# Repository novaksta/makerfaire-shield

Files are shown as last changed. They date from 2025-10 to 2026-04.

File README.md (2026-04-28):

# Game console shield for NUCLEO-F412ZG

It is intended for [MakeCode Arcade](https://arcade.makecode.com/) as F4 target (see available material on (https://arcade.makecode.com/hardware/adding) if you wish to customize),

with additional [lcd module](https://www.laskakit.cz/128x160-barevny-lcd-tft-displej-1-8--spi/)

Available are [bootloader firmware binaries](bootloaders/v2-st7735/bootloader.bin)

There is available kicad project for the board in [pcb foler](pcb) (including [gerbers with BOM](pcb/jlcpcb/production_files/production_files-min.7z) in jlcpcb-friendly format).

There are available [workshop slides](slajdy.pdf) for Maker Faire in Prague 2026 (in czech language) that describes "getting started" process. 

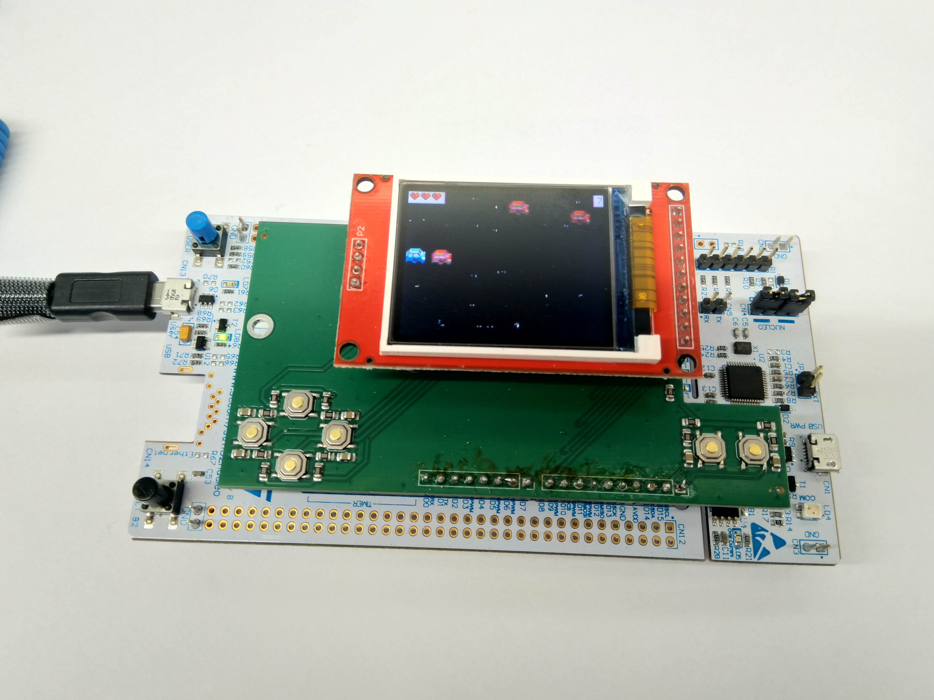
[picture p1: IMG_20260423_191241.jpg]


There are also available workshop materials for Maker Faire in Brno 2025 where used NUCLEO-F411RE/NUCLEO-F401RE -- please see releases section. 

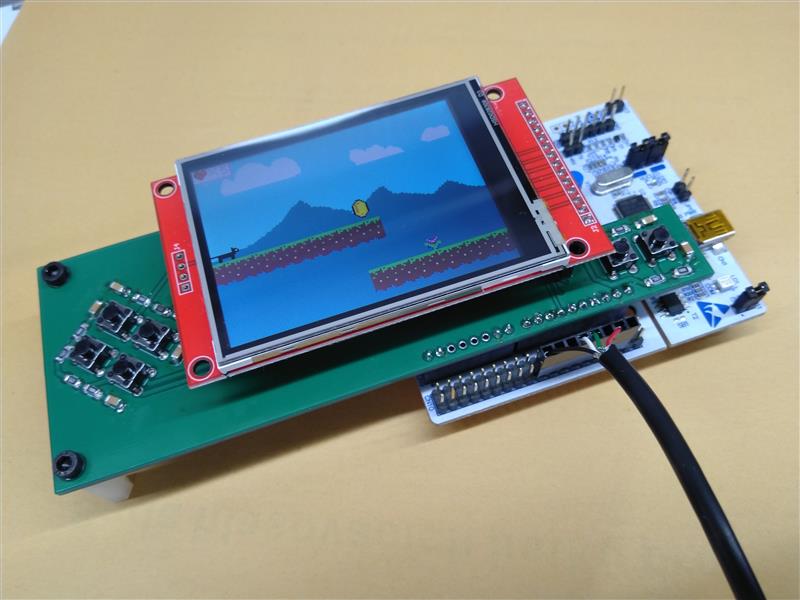
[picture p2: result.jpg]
The result equipped with modules


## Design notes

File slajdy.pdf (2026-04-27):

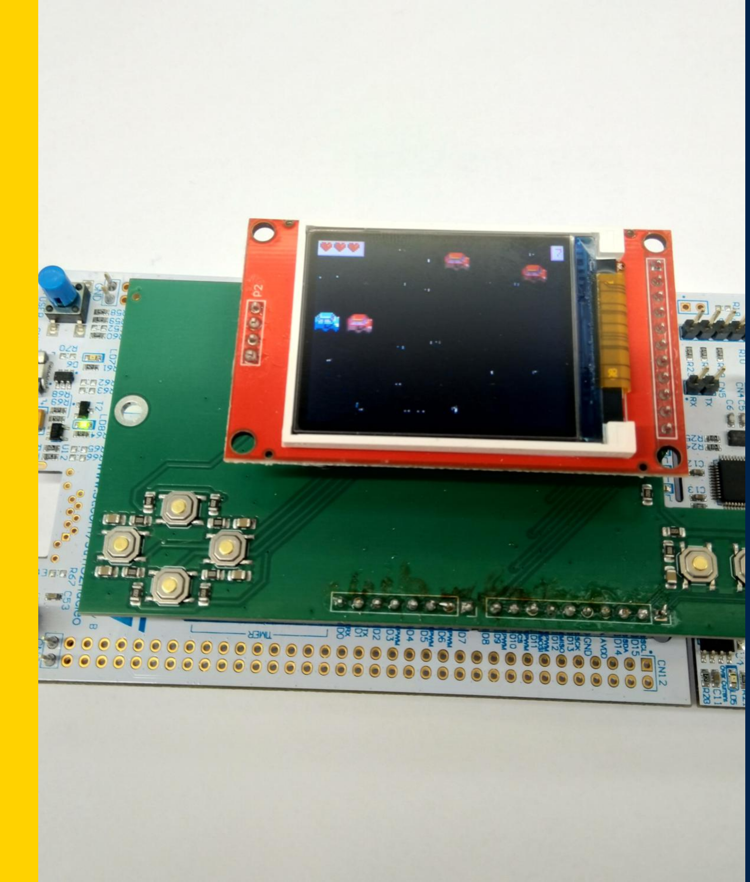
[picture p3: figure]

## Postav a naprogramuj si vlastní herní konzoli s mikrokontrolérem STM32!

Stanislav NOVAK

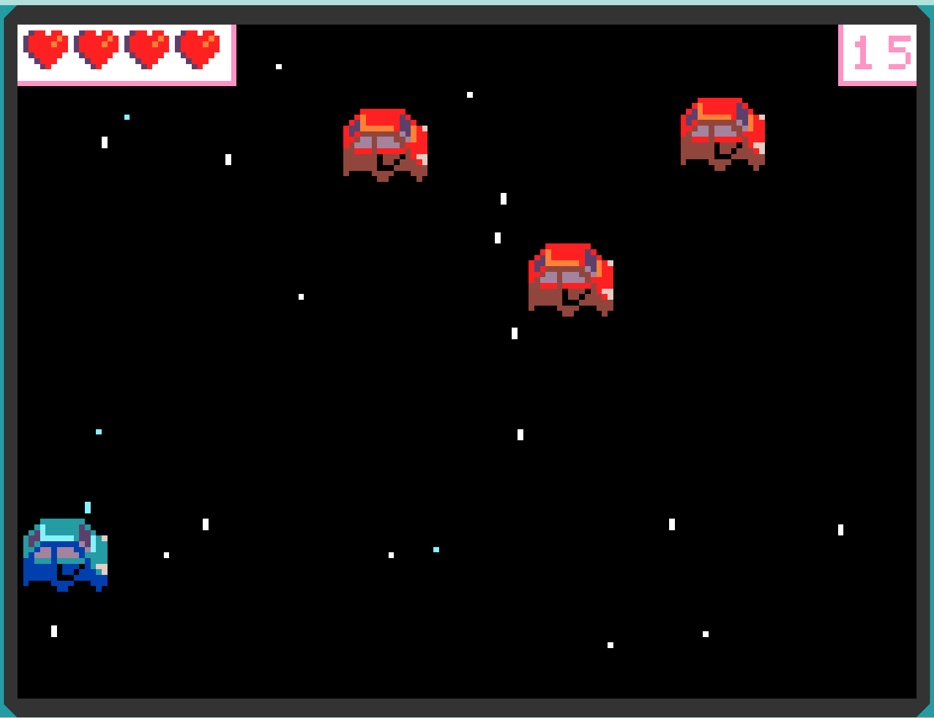
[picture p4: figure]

1

## Agenda

Úvod, predstavení

1.1 | MakeCode Arcade, software
1.2 | Platforma, hardware
2 | Samotný workshop

## Úvod

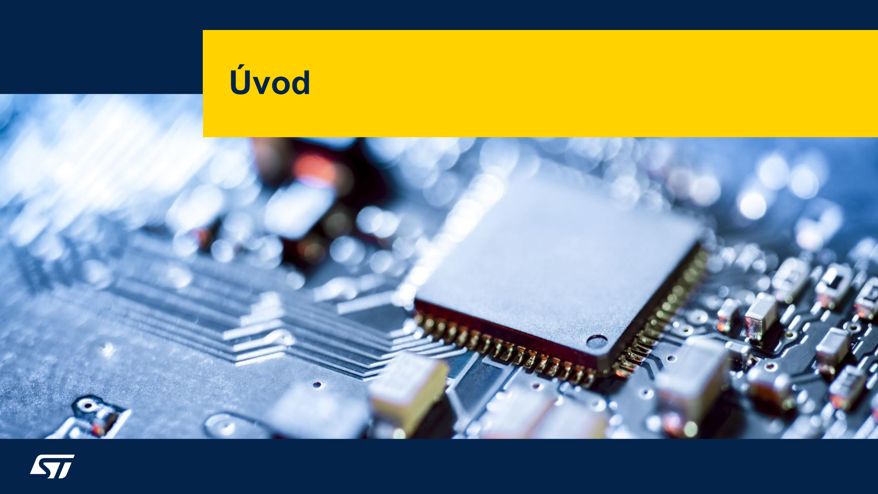
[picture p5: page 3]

## Představení

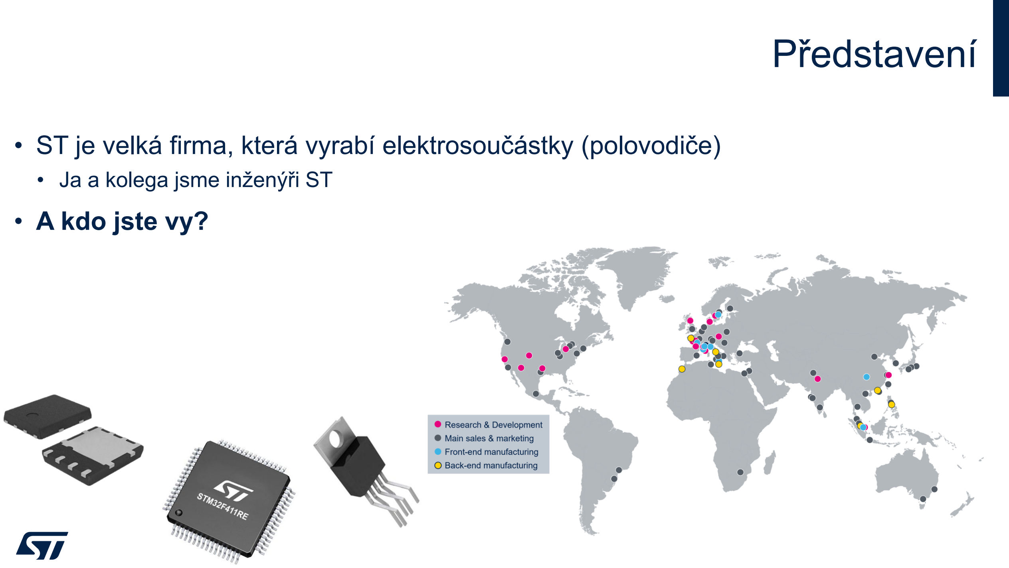
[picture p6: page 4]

- ST je velká firma, která vyrabí elektrosoučástky (polovodiče)
- Ja a kolega jsme inženýři ST
- A kdo jste vy?

- Vyukové prostredí od Microsoftu
- Grafické programovaní, nebo textové (json, python)
- Snadný začátek – intuitivní tahání bloků
- Rozšíření Arcade pro tvorbu her

## MakeCode Arcade

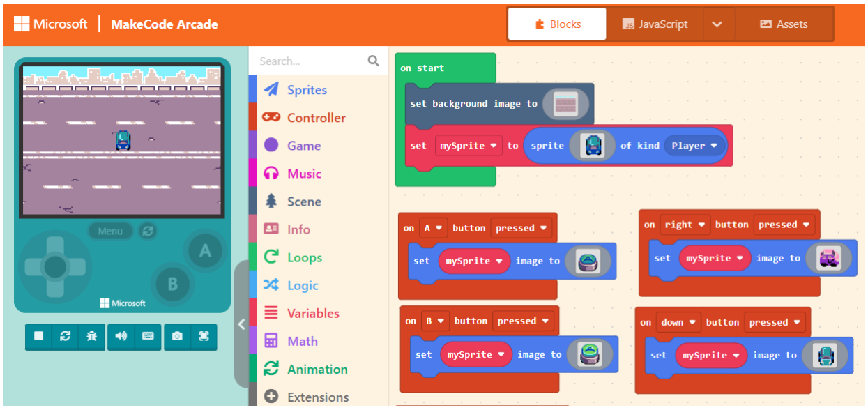
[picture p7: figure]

## Platforma, hardware

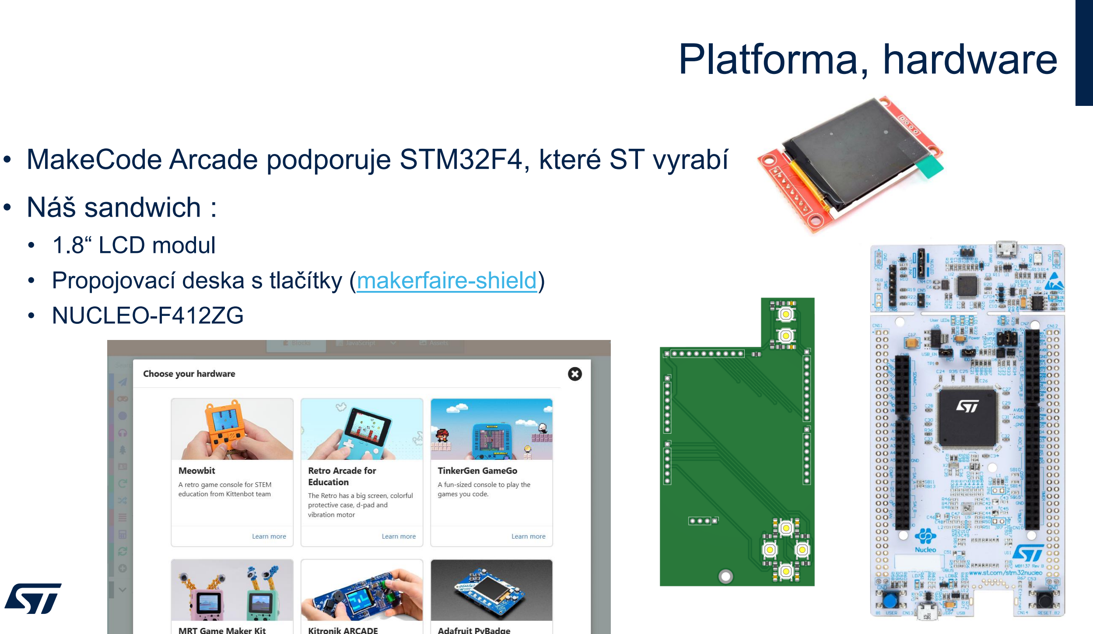
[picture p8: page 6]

- MakeCode Arcade podporuje STM32F4, které ST vyrabí
- Náš sandwich :
- 1.8“ LCD modul
- Propojovací deska s tlačítky (makerfaire (https://github.com/novaksta/makerfaire-shield)- (https://github.com/novaksta/makerfaire-shield)shield) (https://github.com/novaksta/makerfaire-shield)
- NUCLEO-F412ZG

## Workshop

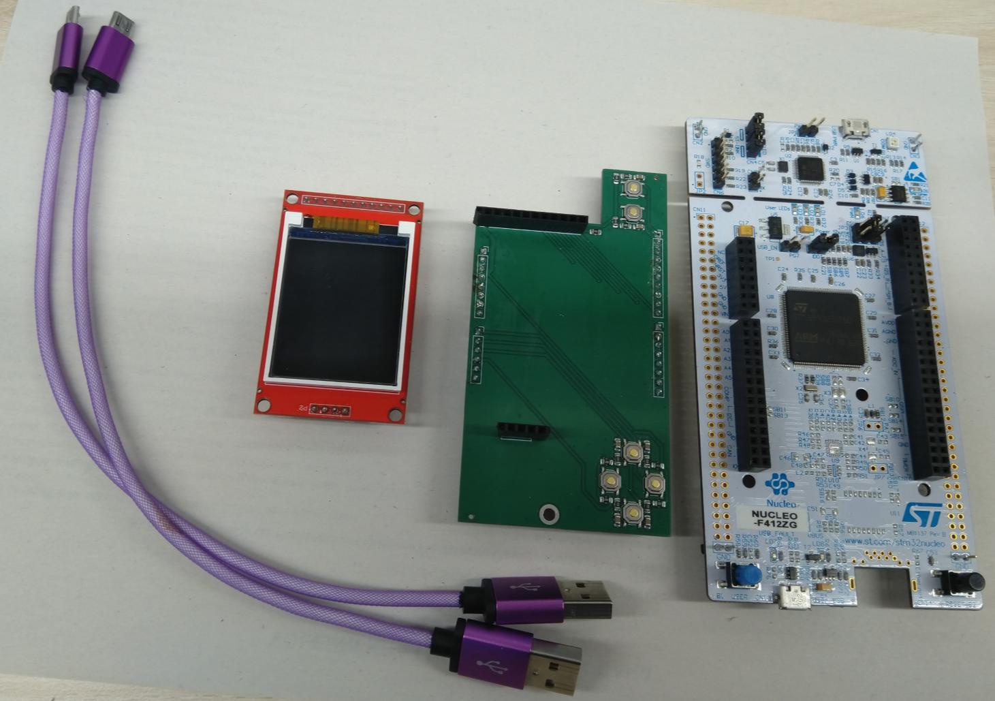
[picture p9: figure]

## Poskládejte si konzoli (v rychlosti)

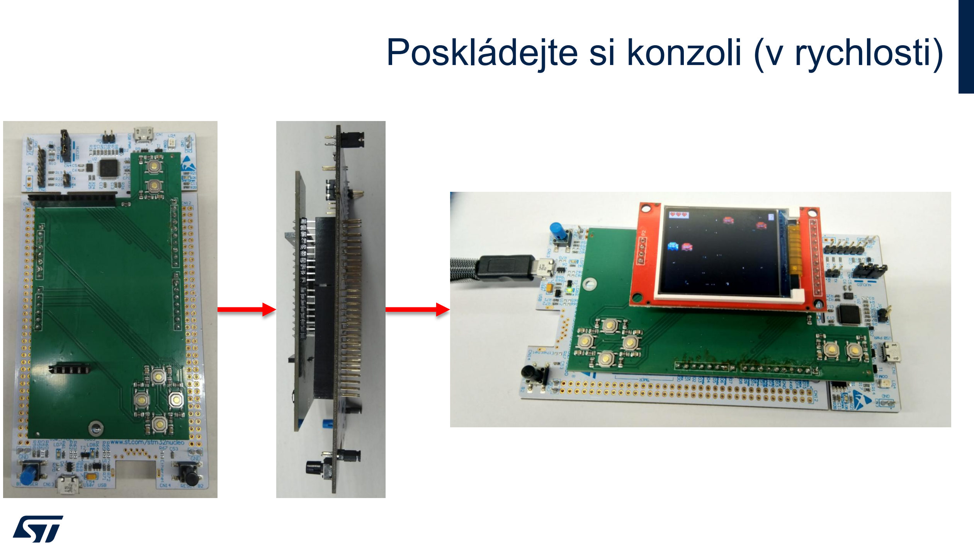
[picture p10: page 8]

## Prvky na konzoli

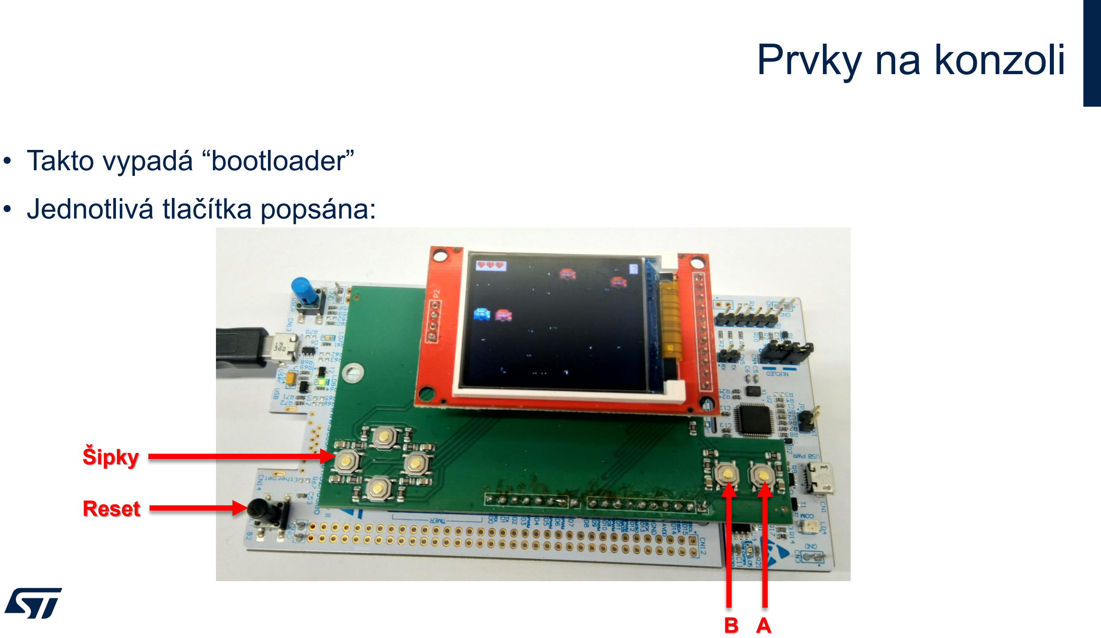
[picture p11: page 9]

- Takto vypadá “bootloader”
- Jednotlivá tlačítka popsána:

B A

Reset

Šipky

- https://arcade.makecode.com

## MakeCode

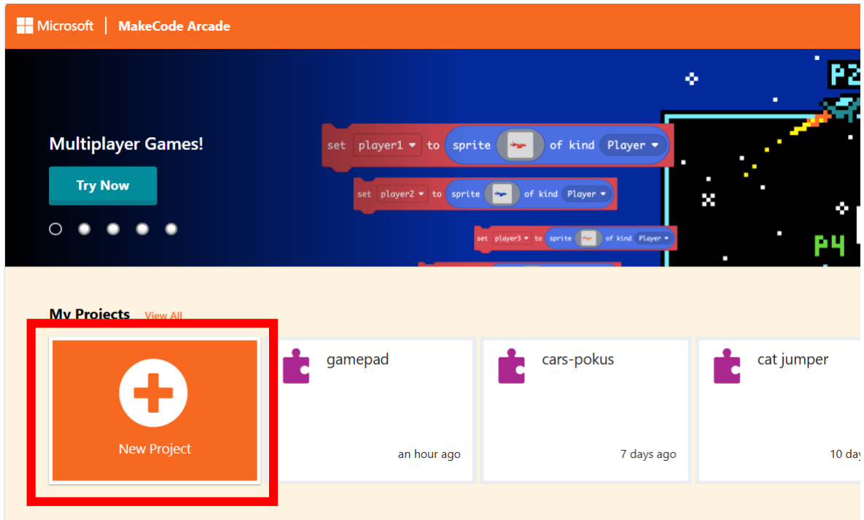
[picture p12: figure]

## Prázdný projekt

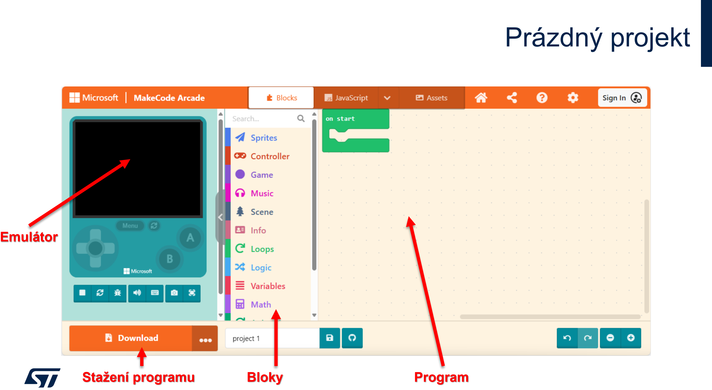
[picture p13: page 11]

Emulátor

Stažení programu | Bloky | Program

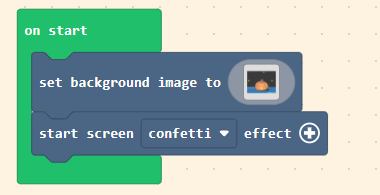
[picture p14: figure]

- Mame start, změníme pozadí a přidáme efekt
- Pri zmáčknutí tlačítka 2, změníme pozadí
- Pri uvolnení nastavíme, jiné
- Můžeme kopírovat

## První program

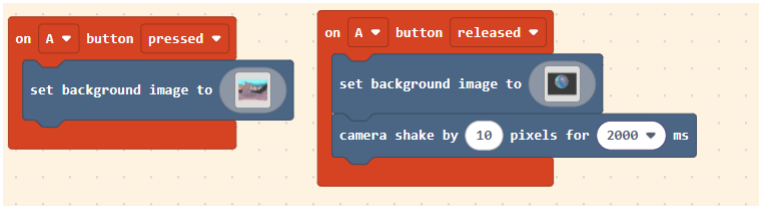
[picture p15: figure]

## Nahrani do desky

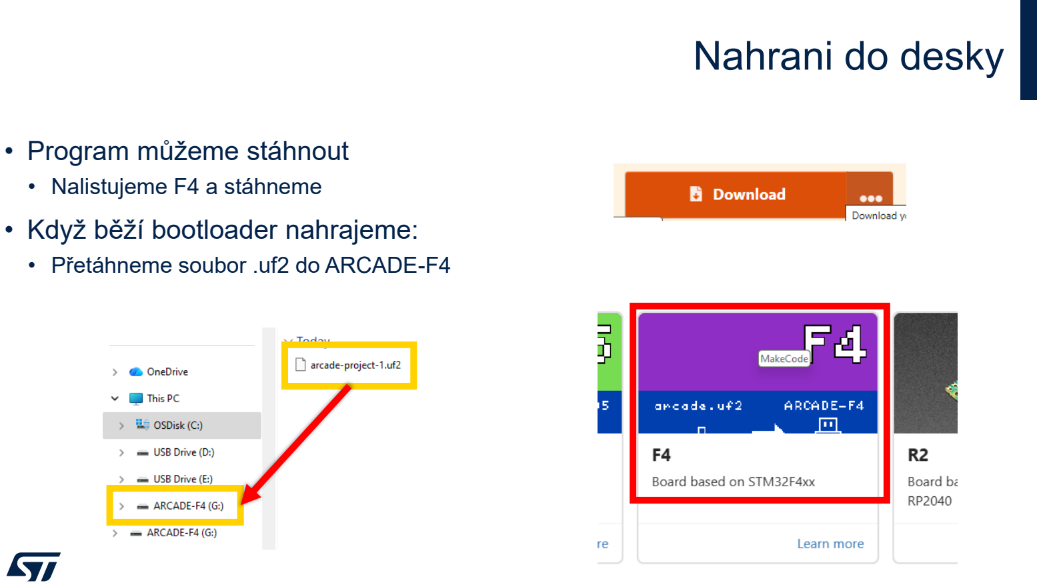
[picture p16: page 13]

- Program můžeme stáhnout
- Nalistujeme F4 a stáhneme
- Když běží bootloader nahrajeme:
- Přetáhneme soubor .uf2 do ARCADE-F4

- Modré auto, které “předjíždí” červená – snažíme se vyhnout
- Modré auto se pohybuje nahoru dolu
- Červená se přibližují zprava
- Vylepšení
- 5 životů
- Score, kolik aut bylo předjeto,
- Efekty
- …

## První hra

## Zakladní program

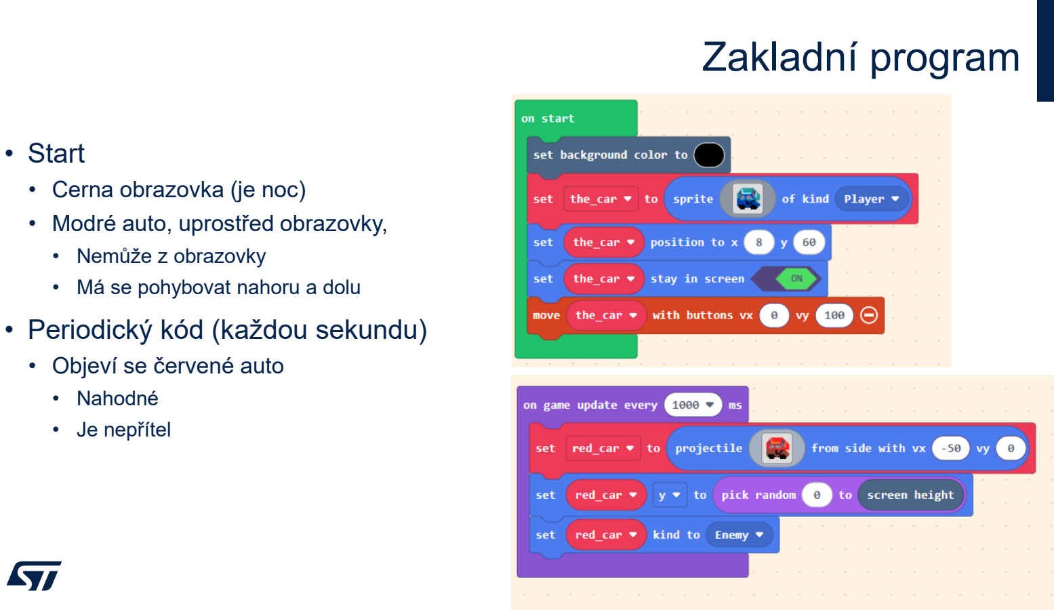
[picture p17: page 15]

- Start
- Cerna obrazovka (je noc)
- Modré auto, uprostřed obrazovky,
- Nemůže z obrazovky
- Má se pohybovat nahoru a dolu
- Periodický kód (každou sekundu)
- Objeví se červené auto
- Nahodné
- Je nepřítel

- Když narzíme,
- Červené auto zmizí
- Odebereme život

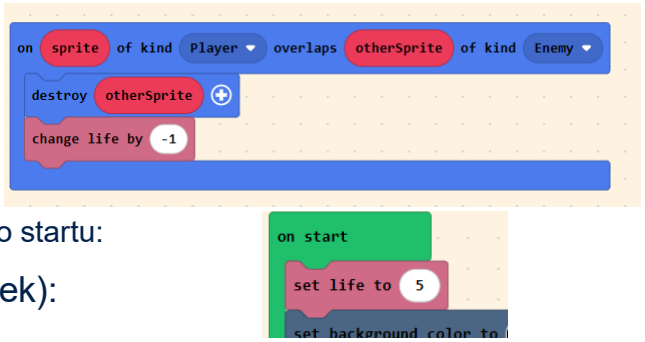
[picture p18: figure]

- Aby se zobrazili životy na obrazovce – přidame do startu:
- Pro score potřebuje definovat hranu (obrázek):
- Když narazí červené auto, přidáme skóre
- Efekty
- Namísto konfet z prvního příkladu můžeme použít blizzard
- Pri kolizi můžeme zatřást obrazovkou
- (další úpravy jsou na Vás)

## Kolize, skóre

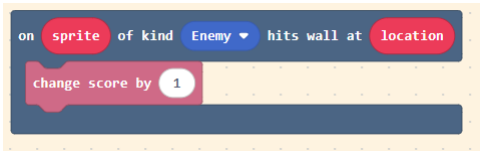
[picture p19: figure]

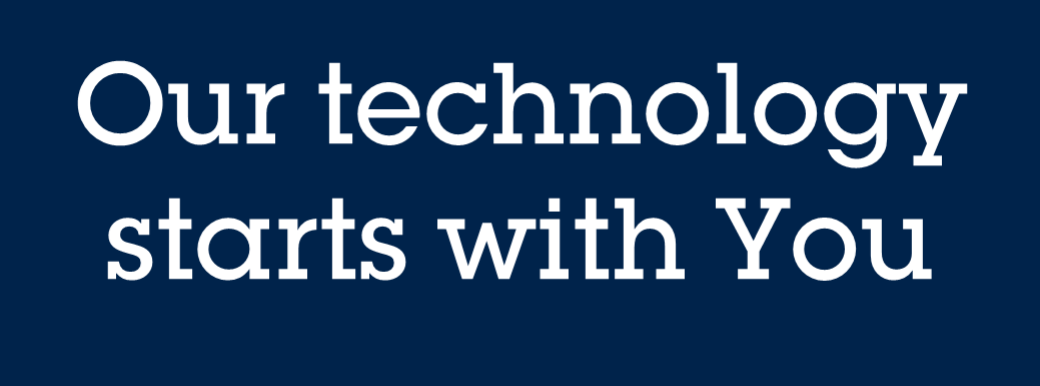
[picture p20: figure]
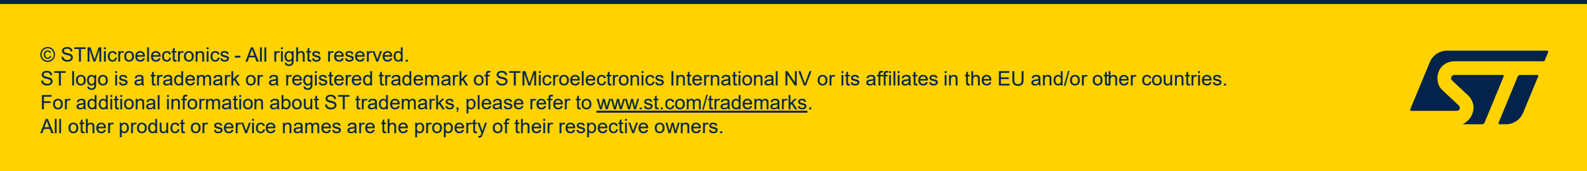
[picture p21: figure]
www.st.com/trademarks

© STMicroelectronics - All rights reserved.
ST logo is a trademark or a registered trademark of STMicroelectronics International NV or its affiliates in the EU and/or other countries. For additional information about ST trademarks, please refer to www.st.com/trademarks.
All other product or service names are the property of their respective owners.

## Find out more at www.st.com

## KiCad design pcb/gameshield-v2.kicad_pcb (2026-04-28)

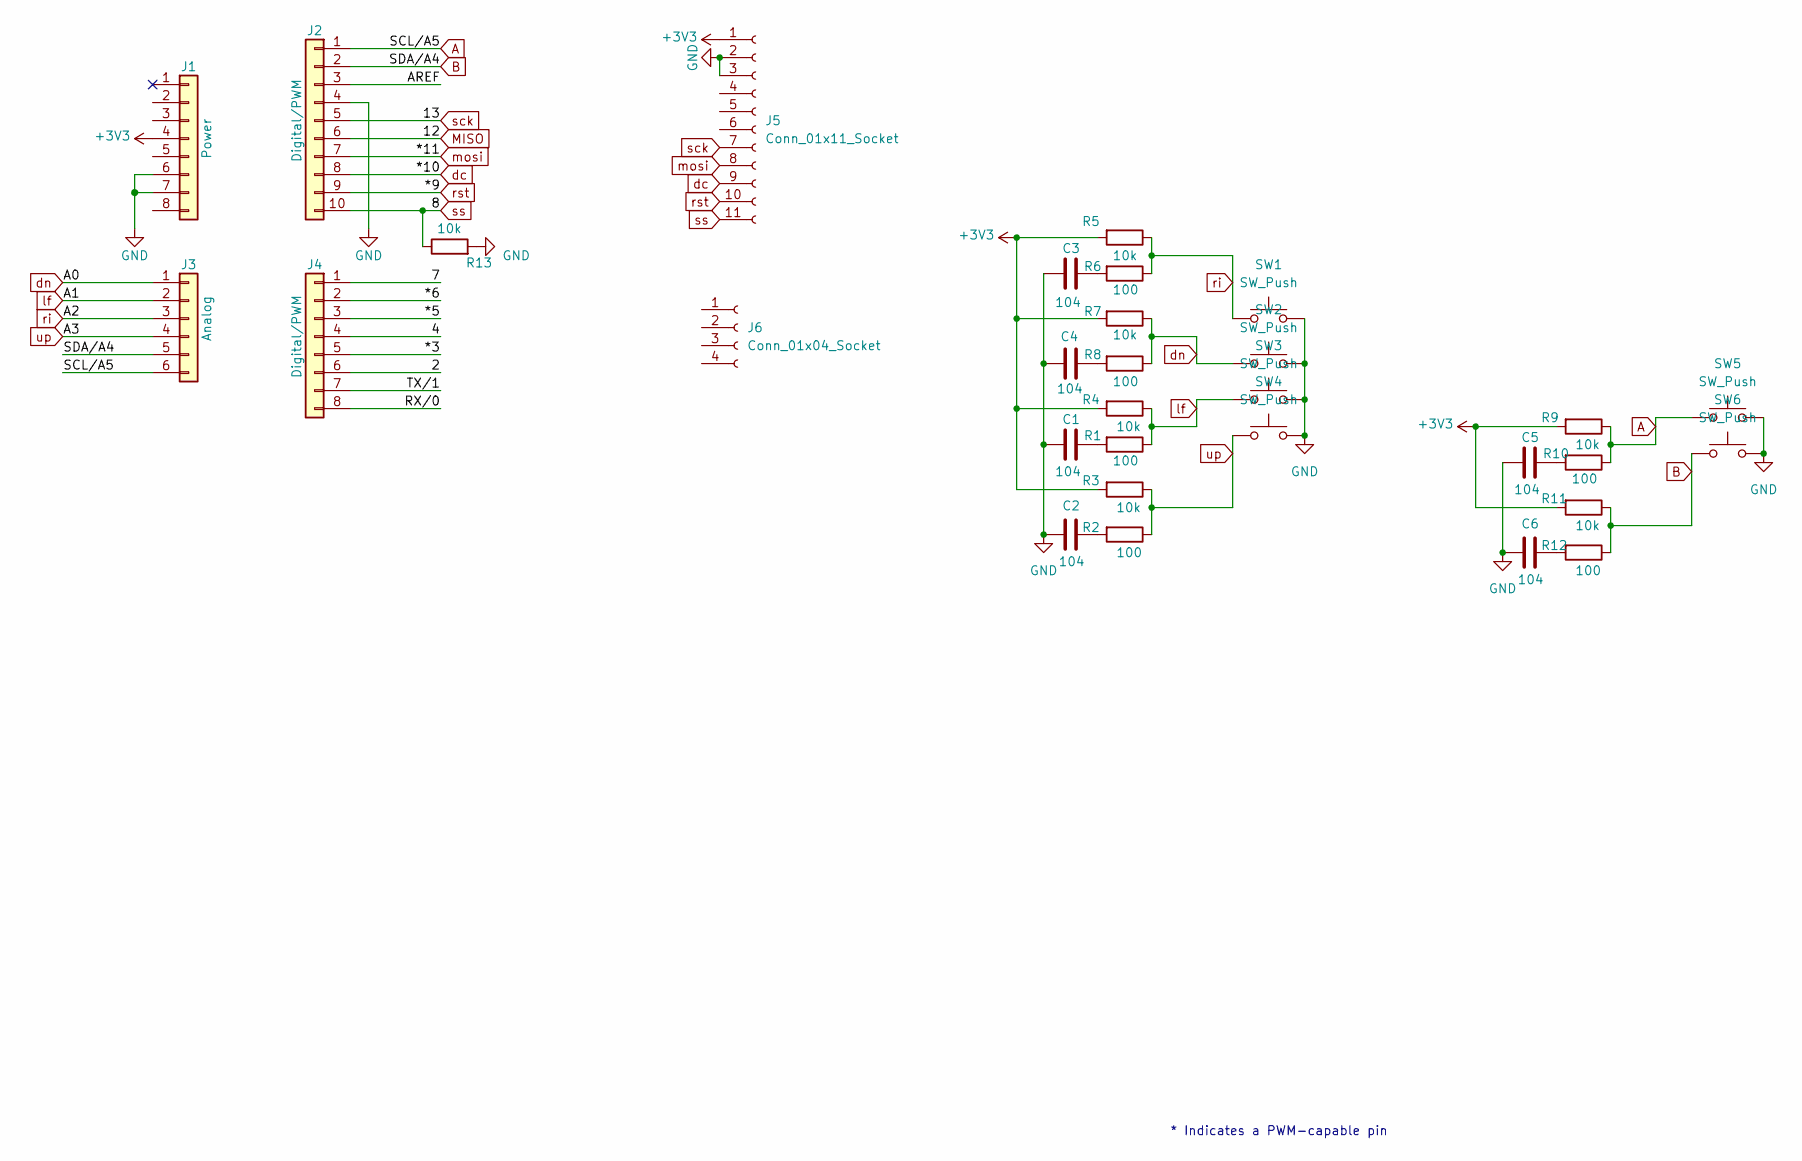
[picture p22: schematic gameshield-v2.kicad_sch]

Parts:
C1, C2, C3, C4, C5, C6: 104; C_0805_2012Metric_Pad1.18x1.45mm_HandSolder
J1: Power; PinHeader_1x08_P2.54mm_Vertical
J2: Digital/PWM; PinHeader_1x10_P2.54mm_Vertical
J3: Analog; PinHeader_1x06_P2.54mm_Vertical
J4: Digital/PWM; PinHeader_1x08_P2.54mm_Vertical
J5: Conn_01x11_Socket; PinHeader_1x11_P2.54mm_Vertical
J6: Conn_01x04_Socket; PinHeader_1x04_P2.54mm_Vertical
R1, R2, R6, R8, R10, R12: 100; R_0805_2012Metric_Pad1.20x1.40mm_HandSolder
R3, R4, R5, R7, R9, R11, R13: 10k; R_0805_2012Metric_Pad1.20x1.40mm_HandSolder
SW1, SW2, SW3, SW4, SW5, SW6: SW_Push; SW_Push_1P1T_XKB_TS-1187A

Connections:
+3V3: J1.4, J5.1, R3.2, R4.2, R5.2, R7.2, R9.2, R11.2
/2: J4.6
/4: J4.4
/7: J4.1
/*3: J4.5
/*5: J4.3
/*6: J4.2
/AREF: J2.3
/RX/0: J4.8
/TX/1: J4.7
A: J2.1, J3.6, R9.1, R10.1, SW5.1
B: J2.2, J3.5, R11.1, R12.1, SW6.1
GND: C1.2, C2.2, C3.2, C4.2, C5.2, C6.2, J1.6, J1.7, J2.4, J5.2, J5.3, R13.2, SW1.2, SW2.2, SW3.2, SW4.2, SW5.2, SW6.2
MISO: J2.6
unnamed: C1.1, R1.2
unnamed: C2.1, R2.2
unnamed: C3.1, R6.2
unnamed: C4.1, R8.2
unnamed: C5.1, R10.2
unnamed: C6.1, R12.2
dc: J2.8, J5.9
dn: J3.1, R7.1, R8.1, SW2.1
lf: J3.2, R1.1, R4.1, SW3.1
mosi: J2.7, J5.8
ri: J3.3, R5.1, R6.1, SW1.1
rst: J2.9, J5.10
sck: J2.5, J5.7
ss: J2.10, J5.11, R13.1
up: J3.4, R2.1, R3.1, SW4.1

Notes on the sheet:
* Indicates a PWM-capable pin

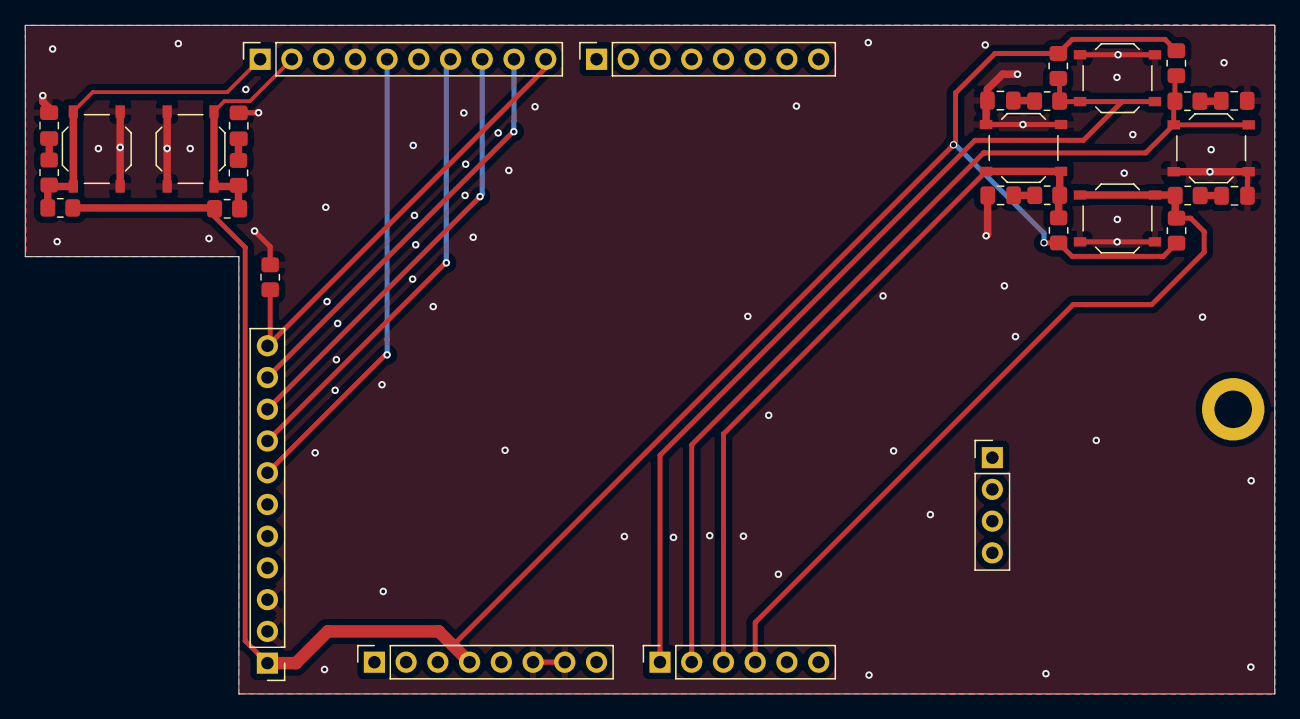
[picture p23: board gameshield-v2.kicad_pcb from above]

Board: 2 copper layers, 100.0 x 53.5 mm, 31 parts (0 on the bottom side), 19 nets.
